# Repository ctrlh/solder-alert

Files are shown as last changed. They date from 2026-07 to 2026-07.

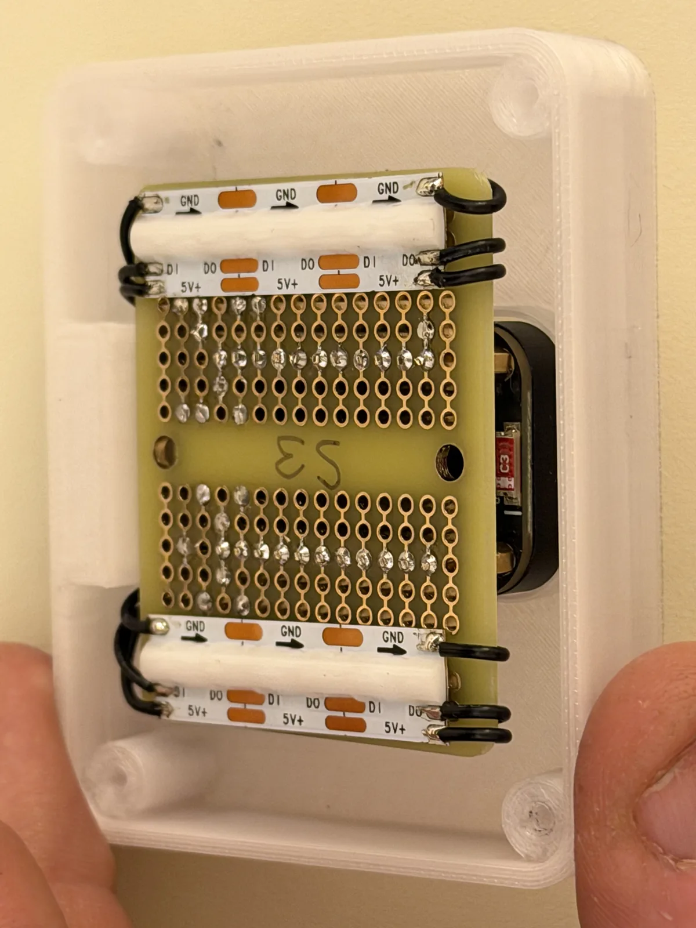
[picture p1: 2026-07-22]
assembly/full/assembly-16.webp

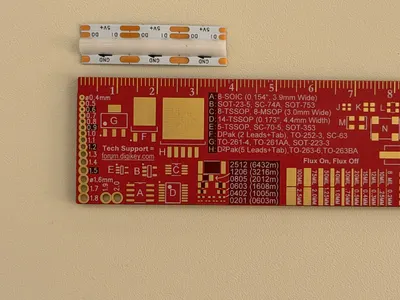
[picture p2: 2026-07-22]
assembly/thumb/assembly-04.webp

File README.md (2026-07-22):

# Solder Alert

An ESPHome-based attention device that supervises a soldering iron's power switch. It counts down the iron's on-time, warns you before the time runs out, lets you add more time from the device, and cuts power if nobody responds — so an iron never gets left on indefinitely.

It pairs with a Home Assistant blueprint that drives a real smart plug or switch and adds an offline safety net: if the device drops off the network or a deadline passes, Home Assistant turns the switch off on its own.

## Hardware

Two board variants build from one shared config:

- **ESP32-S3** — Waveshare ESP32-S3-Touch-LCD-1.47 (8 MB PSRAM). The recommended board.
- **ESP32-C6** — the original prototype board, still supported.

Both variants drive a 172x320 touch LCD and a WS2812 status LED strip, and control a switch or smart plug through Home Assistant.

### Bill of Materials

This is a blinking-lights project, so use whatever you have on hand that's in your junk box.

I wanted these units to look identical so I purchased Waveshare displays.

- [Adafruit Perma-Proto Quarter-sized Breadboard PCB](https://www.adafruit.com/product/1608)
- [ESP32-S3-Touch-LCD-1.47-M](https://www.waveshare.com/esp32-s3-touch-lcd-1.47.htm?sku=31199)
- [ESP32-C6-Touch-LCD-1.47-M](https://www.waveshare.com/esp32-c6-touch-lcd-1.47.htm?sku=31201)
- I used some leftover segments from [a BTF-Lighting WS2812B LED strip](https://www.amazon.com/dp/B0DKSV5TPS) (160 LEDs/meter FCOB, 10mm wide)
- Fine hookup wire (30 AWG)

[Assembly photos](assembly-photos.html) from the prototype and the first "production" units installed at [PDX Hackerspace](https://pdxhackerspace.org/).

A 3D-printable enclosure lives in [`enclosure/`](enclosure/) — OpenSCAD source plus ready-to-print STL and 3MF, sized for the Waveshare display and the quarter-size Adafruit perma-proto board.

## Build and flash

Built with [ESPHome](https://esphome.io/) through the `make` targets in `firmware/`:

```sh
cd firmware
cp secrets.yaml.example secrets.yaml   # then fill in your values
make run BOARD=s3                      # compile, flash, and tail logs (USB)
make run BOARD=c6                      # or the C6 board
```

Run `make` with no target to list everything. The first flash is over USB; later flashes go over WiFi (OTA) once the device is provisioned through its captive portal.

## Secrets

Copy `firmware/secrets.yaml.example` to `firmware/secrets.yaml` and set:

- `api_encryption_key` — generate with `esphome secrets generate-encryption-key`
- `ota_password` — any strong password
- `ap_password` — the captive-portal fallback AP password. The example ships a default (`solder-alert-setup`); change it for anything past a bench setup.

WiFi credentials are not stored in the repo. The device asks for them through its captive portal on first boot.

## Home Assistant

`blueprints/solder-alert-bridge.yaml` bridges the device to a real HA switch and adds the offline and deadline safety fallback.

HA's "Import Blueprint" dialog only accepts a URL — there's no file picker — so to install a local copy you have to place the file directly in your HA config, using the **File Editor** add-on or `scp`:

```text
<config>/blueprints/automation/solder-alert/solder-alert-bridge.yaml
```

HA doesn't watch the filesystem for new blueprints, so afterward reload it from **Developer Tools → YAML** (reload automations / blueprints), or restart HA.

Then create an automation from the blueprint and pick your device, the target switch, and the device's "On-period expires at" sensor. Set the smart plug's power-on state to **off** so it never restores to "on" after a power cut.

## Releases

When a [release](https://github.com/ctrlh/solder-alert/releases) includes prebuilt factory images, flash a `*.factory.bin` directly (with `esptool` or the ESPHome web flasher) — no build needed. Otherwise, build from source with
the steps above.

## License

MIT — see [LICENSE](LICENSE).

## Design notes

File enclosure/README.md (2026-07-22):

# Solder Alert Enclosure

Developed using [OpenSCAD](https://openscad.org).

I recommend printing using transparent or white PETG, which is a bit more flexible. PLA is a second choice.

Designed specifically to fit the 1/4-size Adafruit breadboard and Waveshare 1.47 inch display (ESP32-S3 or ESP32-C6 variants).

It's a tight fit with about 0.5mm of the display proud of the front surface. Angle the USB connector into it's exit slot first, then firmly push down on the other end of the board to complete the insertion.

The cavity for the USB-C connector will fit common USB-whatever-to-USB-C adapters, in addition to the usual USB-C male cables.

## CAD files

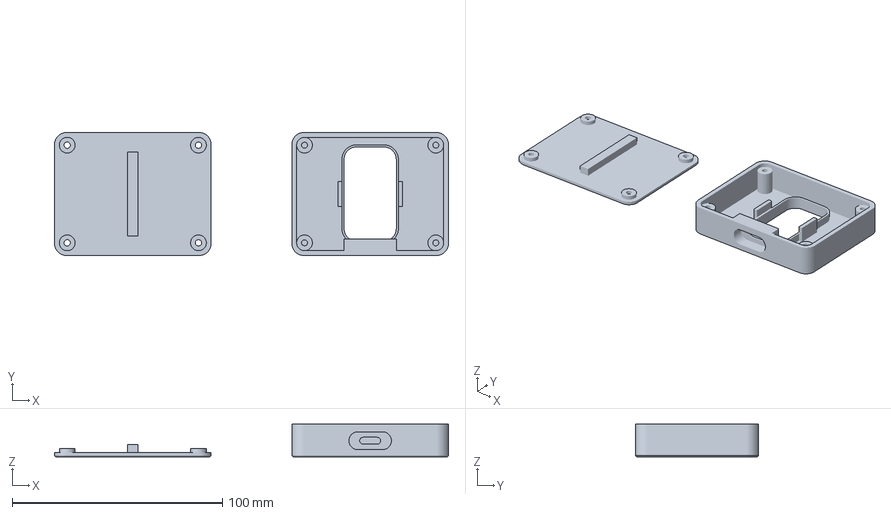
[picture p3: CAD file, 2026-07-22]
enclosure/solder-alert.3mf
187.6 x 58.6 x 15.5 mm

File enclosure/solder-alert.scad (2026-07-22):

// solder-alert.scad
//
// Designed to be printed using transparent or white filament, so the lighting
// shines through with some diffusion.
//
// Screws are M3 x 8mm flat head self-tappers (Philips). The threads on machine
// screws are too fine and will just spin in the guide holes unless their
// diameters are adjusted.
//

tolerance             =  0.15;

display_width         = 24.55 + tolerance * 2;
display_depth         = 44.50 + tolerance * 2;
mcu_lcd_height        =  5.40;
mcu_lcd_proud         =  0.60; // exposed rounding on the front face
mcu_lcd_internal      = (mcu_lcd_height - mcu_lcd_proud);
mcu_pcb_thickness     =  1.20;
mcu_standoff_height   =  4.00;
display_height        = (mcu_lcd_internal + mcu_pcb_thickness + mcu_standoff_height);
display_radius        =  5.75 + tolerance;
retainer_thickness    =  1.00;

rear_pillar_width     =  5.00;
rear_pillar_depth     = 40.00;
rear_pillar_height    =  3.90;

pcb_thickness         =  1.60;

wall_thickness        =  2.00;
wall_chamfer          =  0.60;

front_pillar_width    =  2.00;
front_pillar_depth    = 12.00;
front_pillar_height   = (display_height - wall_thickness);

// Internal dimensions
internal_box_width    = 70.00;
internal_box_depth    = 54.00;
internal_box_height   = (front_pillar_height + pcb_thickness + rear_pillar_height);

screw_diameter        =  3.00; // M3
screw_radius          = (screw_diameter / 2);
screw_pilot_diameter  = (screw_diameter * 0.95);
screw_head_diameter   =  5.60; // M3 => dk.max = 5.6
screw_shoulder        =  0.25;
screw_post_diameter   = (screw_diameter * 2.5);
screw_post_split      =  2.00;

box_radius            = (screw_post_diameter / 2 + wall_thickness); // M3 flat head

usb_block_depth       = (internal_box_depth - display_depth) / 2 + retainer_thickness;

usb_c_width           = 10.00;
usb_c_diameter        =  3.30;
usb_c_depth           = 10.00;

usb_cavity_width      = 16.00;
usb_cavity_height     =  8.50;
usb_cavity_v_center   = (mcu_lcd_internal + mcu_pcb_thickness + usb_c_diameter / 2);

ziptie_slot_width     = 1.5;
ziptie_slot_depth     = 7.0;
ziptie_mount_height   = (internal_box_height - mcu_standoff_height) - usb_c_diameter / 2 - wall_thickness / 2;
ziptie_mount_width    = 8.0;
ziptie_mount_depth    = (ziptie_slot_depth * 1.5);

epsilon               =  0.01;
$fn                   = 60;

// 2D rounded rectangle in XY.
module rounded_rect(size, radius, center = true) {
  offset(r = radius) {
    offset(delta = -radius) {
      square([size[0], size[1]], center = center);
    }
  }
}

// --- 2D rounded rectangle, centered ---
module _rounded_rect_2d(size, radius, center = true) {
  // Caveat: requires radius < min(width, length) / 2 to avoid
  // degenerate geometry from offset on a zero or negative square.
  assert(radius < min(size[0], size[1]) / 2, "Degenerate geometry from zero/negative square");

  offset(r = radius) {
    square([size[0] - 2 * radius, size[1] - 2 * radius], center = center);
  }
}

// 3D rounded box (rounded in XY, flat in Z).
module rounded_box(size, radius, center = true) {
  linear_extrude(height = size[2], center = center) {
    rounded_rect([size[0], size[1]], radius, center);
  }
}

// --- Chamfered extrusion via Minkowski with a 45 degree bicone ---
// The bicone kernel adds edge_chamfer to all XY dimensions and
// 2 * edge_chamfer to Z height, so the base shape is reduced to
// compensate.  The result is a body with the same nominal outer
// dimensions but 45 degree chamfers on every horizontal edge,
// blending smoothly into the rounded corners.
// Caveat: Minkowski is computationally expensive in preview mode.
// Reduce circle_fragments if preview is slow.
module _chamfered_extrude(width, length, height, radius, chamfer) {
  circle_fragments = 36;     // $fn for cylinders and arcs
  minkowski() {
    linear_extrude(height = height - 1 * chamfer) {
      _rounded_rect_2d(
        [width  - 1 * chamfer, length - 1 * chamfer],
        max(0, radius - chamfer)
      );
    }
    // Bicone: two cones base-to-base, total height = 2 * chamfer
    hull() {
      cylinder(r1 = 0, r2 = chamfer, h = chamfer, $fn = circle_fragments);
//      translate([0, 0, chamfer]) {
//        cylinder(r1 = chamfer, r2 = 0, h = chamfer, $fn = circle_fragments);
//      }
    }
  }
}

module _box_frame() {
  translate([0, 0, (internal_box_height + wall_thickness) / 2]) {
    difference() {
      // Outer box
      color("white")
//      rounded_box(
//        size = [
//          internal_box_width + wall_thickness * 2,
//          internal_box_depth + wall_thickness * 2,
//          internal_box_height + wall_thickness
//        ],
//        radius = box_radius,
//        center = true
//      );
        translate([
          0,
          0,
          -(internal_box_height + wall_thickness) / 2
        ]) {
          _chamfered_extrude(
            internal_box_width + wall_thickness * 2,
            internal_box_depth + wall_thickness * 2,
            internal_box_height + wall_thickness,
            box_radius,
            wall_chamfer);
        }

      // Remove inner box
      translate([0, 0, wall_thickness / 2]) {
        color("gray")
        rounded_box(
          size = [
            internal_box_width,
            internal_box_depth,
            internal_box_height + epsilon
          ],
          radius = box_radius - wall_thickness,
          center = true
        );
      }
    }
  }
}

module _display_retaining_wall() {
  _internal_box_height = mcu_lcd_internal + mcu_pcb_thickness + epsilon * 2;
  // Retaining walls for display
  translate([
    0,
    0,
    _internal_box_height / 2 + epsilon
   ]) {
    color("blue")
    rounded_box(
      size = [
        display_width + retainer_thickness * 2,
        display_depth + retainer_thickness * 2,
        _internal_box_height
      ],
      radius = display_radius + retainer_thickness,
      center = true
    );
  }
}

module _display_cutout() {
  usb_gap = mcu_standoff_height - usb_c_diameter;

  translate([
    0,
    0,
    display_height / 2 - usb_gap / 2 // - epsilon
   ]) {
    rounded_box(
      size = [display_width, display_depth, display_height - usb_gap + epsilon * 2],
      radius = display_radius,
      center = true
    );
  }
}

module _front_pillars() {
  front_pillar_x_ofs = display_width / 2 + retainer_thickness + front_pillar_width / 2;
  for(x_ofs = [-front_pillar_x_ofs, +front_pillar_x_ofs]) {
    translate([
      x_ofs,
      0,
      front_pillar_height / 2 + wall_thickness - epsilon
    ]) {
      color("red")
      cube([
        front_pillar_width,
        front_pillar_depth,
        front_pillar_height + epsilon
      ], center = true);
    }
  }
}

module _screw_posts() {
  x_ofs = internal_box_width / 2 + wall_thickness - box_radius;
  y_ofs = internal_box_depth / 2 + wall_thickness - box_radius;
  z_ofs = (internal_box_height / 2 + wall_thickness / 2) - epsilon;

  color("green")
  for(x = [-x_ofs, +x_ofs]) {
    for(y = [-y_ofs, +y_ofs]) {
      translate([x, y, z_ofs]) {
        difference() {
          cylinder(
            h = internal_box_height - screw_post_split + epsilon,
            d = screw_diameter * 2.5,
            center = true
          );
          translate([0, 0, epsilon]) {
            cylinder(
              h = internal_box_height - screw_post_split + epsilon * 2,
              d = screw_pilot_diameter,
              center = true
            );
          }
        }
      }
    }
  }
}

module _usb_block() {
  color("brown")
  translate([
    0,
    -display_depth / 2 - usb_block_depth / 2 + retainer_thickness - epsilon,
    (internal_box_height / 2) + wall_thickness
  ]) {
    cube(
      [
        display_width,
        usb_block_depth + epsilon,
        internal_box_height + epsilon
      ],
      center = true);
  }
}

module _usb_c_outline() {
  color("yellow")
  translate([
    0,
    -display_depth / 2,
    usb_cavity_v_center
  ])
  rotate([90, 0, 0])
  hull() {
    translate([-usb_c_width / 2 + usb_c_diameter / 2, 0, 0]) {
      cylinder(h = usb_c_depth, d = usb_c_diameter, center = true);
    }
    translate([usb_c_width / 2 - usb_c_diameter / 2, 0, 0]) {
      cylinder(h = usb_c_depth, d = usb_c_diameter, center = true);
    }
  }
}

module _usb_cavity() {
  _depth = usb_block_depth + wall_thickness;
  color("purple")
  translate([
    0, // (internal_box_width + (wall_thickness) * 2) / 2,
    -display_depth / 2 - retainer_thickness - _depth / 2 - epsilon,
    usb_cavity_v_center
  ]) {
    rotate([90, 0, 0]) {
      hull() {
        translate([-usb_cavity_width / 2 + usb_cavity_height / 4, 0, 0]) {
          cylinder(h = _depth, d = usb_cavity_height, center = true);
        }
        translate([+usb_cavity_width / 2 - usb_cavity_height / 4, 0, 0]) {
          cylinder(h = _depth, d = usb_cavity_height, center = true);
        }
      }
    }
  }
}
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

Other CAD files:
enclosure/solder-alert.stl

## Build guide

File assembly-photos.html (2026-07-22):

Solder Alert · Build Log

# Assembling the first unit

A run of snapshots from building the first "production" Solder Alert, plus one note carried over from the C6 prototype.

Click a frame · or step with ← →

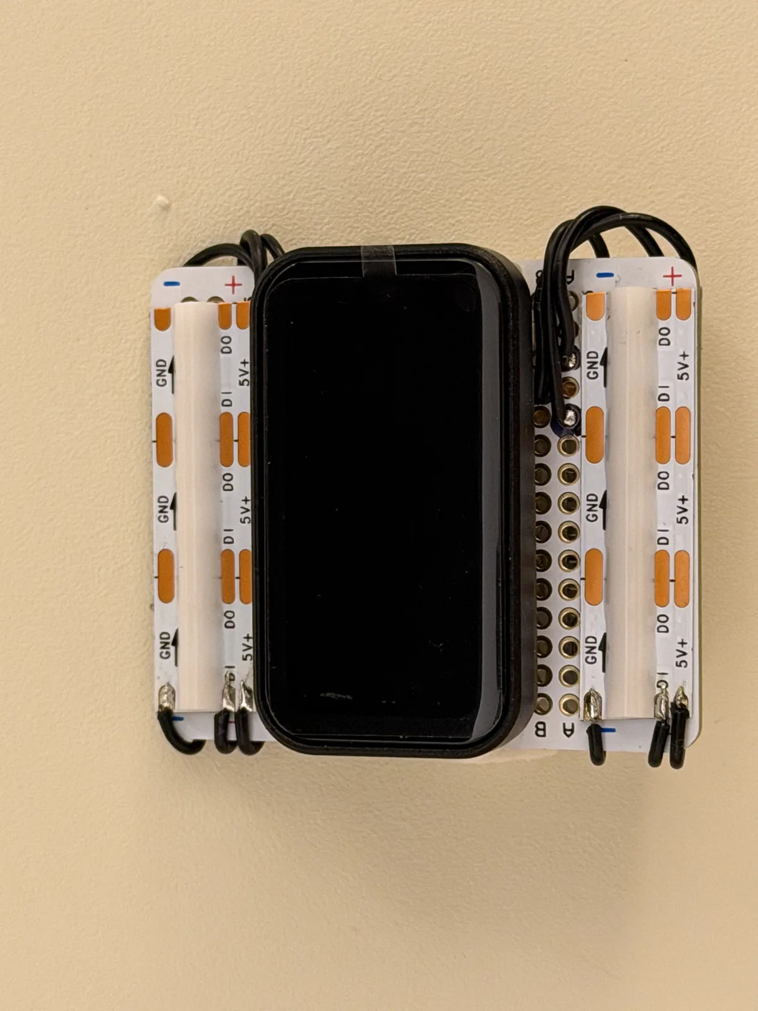
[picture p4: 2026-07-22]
assembly/full/assembly-15.webp

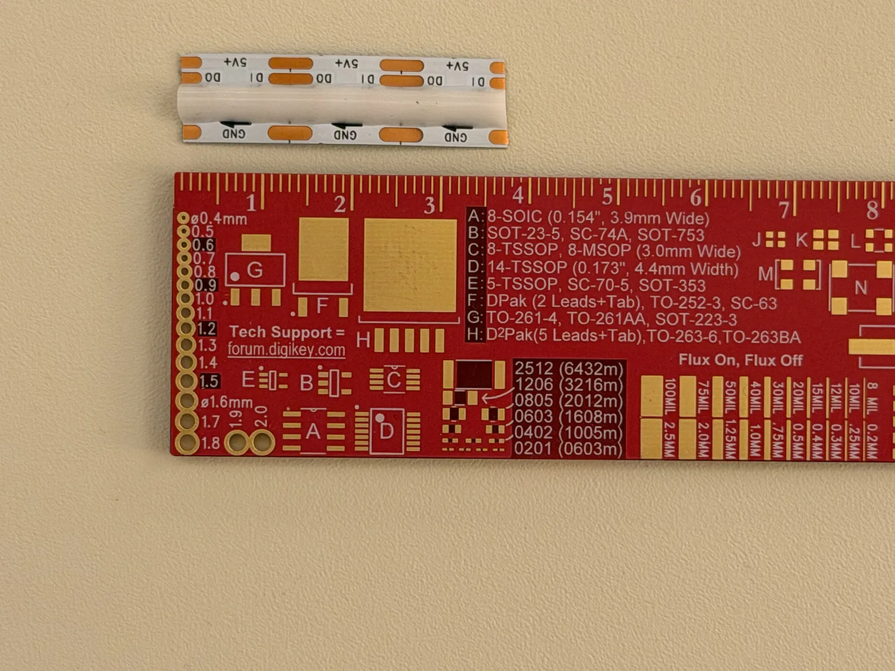
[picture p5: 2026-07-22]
assembly/full/assembly-04.webp

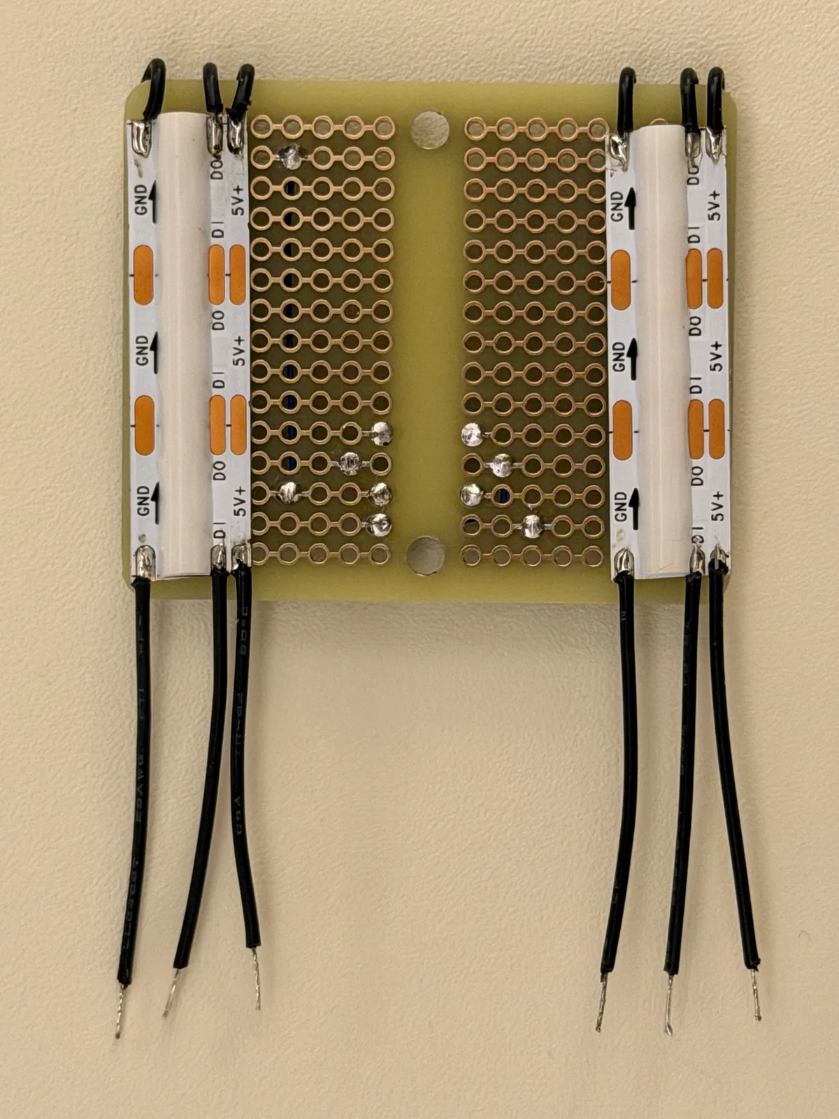
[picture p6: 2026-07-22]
assembly/full/assembly-13.webp

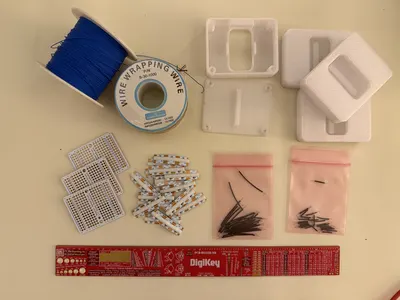
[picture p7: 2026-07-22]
assembly/thumb/assembly-01.webp

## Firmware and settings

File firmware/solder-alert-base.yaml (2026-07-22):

# Solder Alert — Attention Device firmware (shared base)
#
# Board-agnostic config shared by every board variant. Do NOT build this
# file directly — build a board entrypoint (solder-alert-c6.yaml /
# solder-alert-s3.yaml), which supplies the `substitutions:` pin map, the
# `esp32:`/`psram:` blocks, and exactly one orientation package. See
# docs/firmware-plan-v2.0.md §3.
#
# The orientation seam: this base owns the `orientation` global, the
# `apply_orientation` script (global → set_rotation), and the on_touch
# zone-swap. Each variant package supplies `refresh_orientation` (the
# board-specific source: IMU accel on C6, manual select on S3), which the
# base calls on boot and on wake.

# Vertical UI zone boundaries (LOGICAL px, top-down) shared by the display
# layout and the on_touch handler so the two can't drift. on_touch maps raw
# touch.y into logical space (undoing the 180° display flip) before applying
# these, so the bands need NOT be symmetric — they track the visual layout.
substitutions:
  zone_top_px: "104"   # logical y < this → top (countdown); also the extend button's top edge
  zone_mid_px: "192"   # logical y < this → middle (extend); else bottom (power)

esphome:
  name: ${name}
  # Append the last 3 MAC bytes to the node name (e.g. solder-alert-a1b2c3)
  # so each physical board is a distinct ESPHome node / mDNS host. Without
  # this, every board shares the name "solder-alert" and HA "migrates" the
  # integration onto whichever board booted last instead of adding it as a
  # new device. friendly_name is left un-suffixed (HA disambiguates devices
  # by their unique node name, not the friendly label).
  name_add_mac_suffix: true
  friendly_name: ${friendly_name}
  min_version: 2026.6.4
  project:
    name: ctrlh.solder-alert
    version: "${fw_version}"
  on_boot:
    - priority: 200
      then:
        # Publish initial state entity values so HA sees real values
        # instead of "unknown" until the state machine takes over.
        - text_sensor.template.publish:
            id: state_sensor
            state: "boot"
        - sensor.template.publish:
            id: remaining_seconds
            state: 0
        # Clear any stale watchdog deadline so a reboot never leaves HA
        # armed against an expiry from before the crash (plan v1.2 §4.4).
        - text_sensor.template.publish:
            id: on_period_expires_at
            state: ""
        - binary_sensor.template.publish:
            id: display_on
            state: true
        # Assume the target switch is available and off until the
        # blueprint tells us otherwise. Without these publishes we'd
        # trip the OFFLINE overlay and the reconnect-safety off spam
        # while no blueprint exists.
        - binary_sensor.template.publish:
            id: switch_available
            state: true
        - text_sensor.template.publish:
            id: commanded_switch_state
            state: "off"
        - light.turn_on:
            id: backlight
            brightness: 80%
        # Startup R/G/B LED test (plan §6). Gated by the "Startup LED
        # test" switch so it can be silenced later without a reflash.
        - if:
            condition:
              switch.is_on: cfg_startup_led_test
            then:
              - light.turn_on:
                  id: led_strip
                  brightness: 40%
                  red: 1.0
                  green: 0.0
                  blue: 0.0
                  transition_length: 0s
              - delay: 500ms
              - light.turn_on:
                  id: led_strip
                  brightness: 40%
                  red: 0.0
                  green: 1.0
                  blue: 0.0
                  transition_length: 0s
              - delay: 500ms
              - light.turn_on:
                  id: led_strip
                  brightness: 40%
                  red: 0.0
                  green: 0.0
                  blue: 1.0
                  transition_length: 0s
              - delay: 500ms
              - light.turn_off:
                  id: led_strip
                  transition_length: 0s
        # Hand off to the state-driven addressable effect. Runs from
        # here until reboot; per-state colors + timing live in the
        # effect lambda in the light: block.
        - light.turn_on:
            id: led_strip
            brightness: 100%
            effect: state_effect
        # Orientation seam (plan v2.0 §3.2). The board's variant package
        # supplies refresh_orientation: it resolves the current
        # orientation (IMU accel on C6, manual select on S3), stores it
        # in the `orientation` global, and applies the runtime display
        # flip via apply_orientation.
        - script.execute: refresh_orientation
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

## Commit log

2026-07-22 Initial public release
    [solder-alert.3mf, solder-alert.scad, solder-alert.stl]
2026-07-22 Document the 3D-printable enclosure
